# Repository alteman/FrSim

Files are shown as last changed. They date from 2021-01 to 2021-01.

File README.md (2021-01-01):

# FrSim - an STM32 wireless flight simulator USB dongle for FrSky radios

## Introduction

FrSim is a project to create a cheap and easy to build DIY wireless USB receiver dongle that supports FrSky D8/D16 protocols.
BOM is $4, all parts are readily available, no SMD soldering needed.

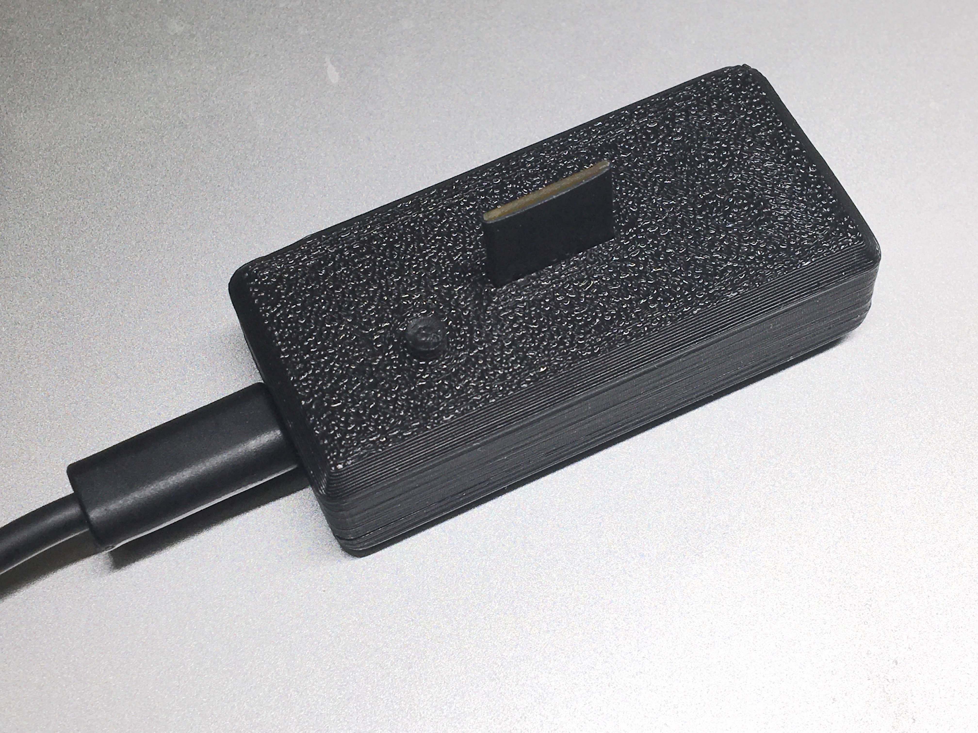
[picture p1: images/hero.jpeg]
Image of FrSim dongle in a 3D printed case


## Why make another sim dongle?

There are existing Arduino based dongles available. I don't like Arduino and didn't have any USB Arduino boards on hand, so that was out.  
There are projects that include custom PCBs, but that seemed too involved for a project that was supposed to save me the cost of a proper $20 dongle.  
There might be some projects that fit the criteria but I missed. Anyway, I didn't spend too much time on this one, and enjoyed most of it, so that wasn't a waste :)

## Parts

- An STM32 Blue Pill board (STM32F103C8T6)
- A CC2500 RF module
- That's it!
- (Optional) a bind button. I cut the Reset button trace and reused it. You might have a pushbutton or a Reed switch handy.

## Building firmware

Currently you have to use STM32CubeIDE to build it. I'm sorry. I'll add a dockerfile if I see any stars or forks :) Or submit a PR yourself!

## Flashing firmware

You can use dfu-util to flash firmware using boot0 jumper to enter DFU. I think the best way is using Betaflight flasher - everyone already have Betaflight installed and it's pretty user friendly. Just go to Firmware tab, press the Local button and load ccsim.hex after connecting the board in DFU mode.

## Schematics

You need to connect STM32 pins to the RF module according to the following 

### STM32 pins

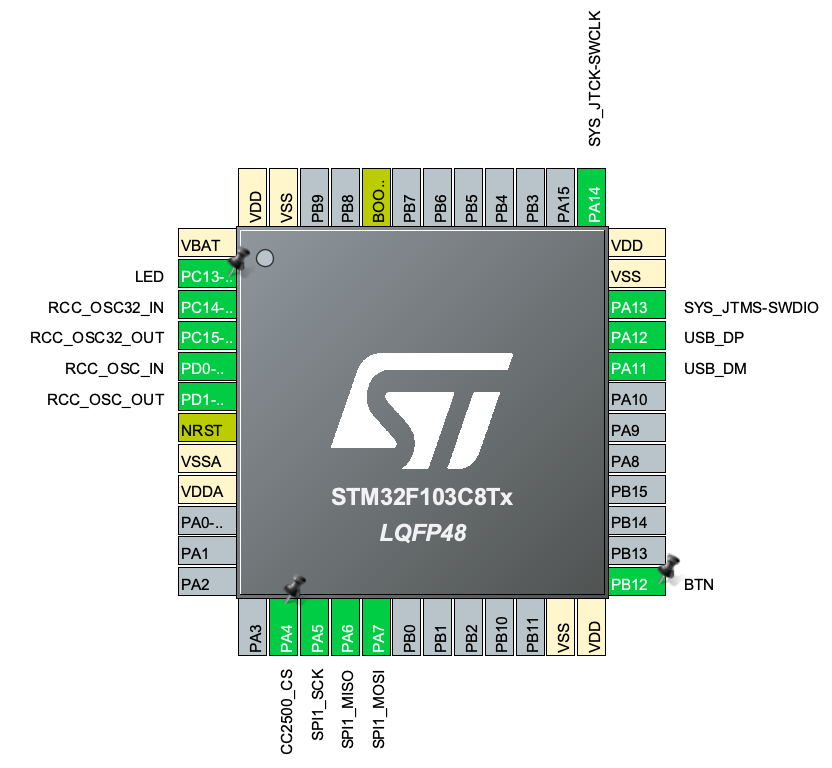
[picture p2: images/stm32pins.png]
Screenshot of STM32 pins with assignments


### CC2500 module pins

24TRGC2 - that's the module I used. If yours looks different, please research its pinout before it goes puff.

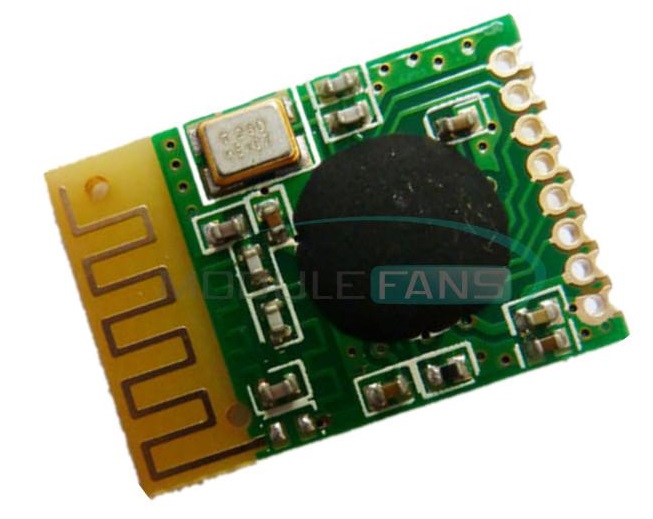
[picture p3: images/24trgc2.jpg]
Image of 24TRGC2 CC2500 module - front

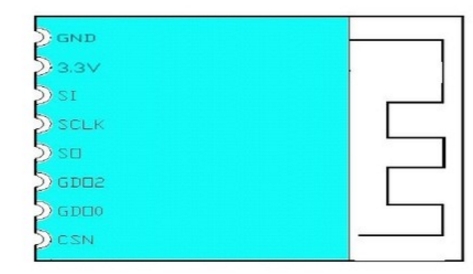
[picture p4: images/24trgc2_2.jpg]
Image of 24TRGC2 CC2500 module - back

- GND
- 3.3V
- SI - SPI MOSI
- SCLK - SPI CLK
- SO - MISO
- GDO2 - N/C
- GDO0 - N/C
- CSN - SPI chip select (inverted)

### Connections
- PA4 to CC2500_CSN
- PA5 to CC2500_CLK
- PA6 to CC2500_MISO
- PA7 to CC2500_MOSI
- PB12 to a pushbutton to GND.

## CAD files

[CAD](CAD) - CAD files (Fusion 360 source and STLs) for the case

## Using the damn thing

### Pairing
- Connect to USB while pressing the bind button
- Press Bind on the radio and wait for it to bind
- Unplug and re-plug the dongle

### RX mode
FrSky receiver mode is set to D16 V2 FCC in [frsky_rx.c](Core/Src/frsky_rx.c):  
`static uint8_t frsky_rx_format = FRSKY_RX_D16v2FCC;`.  
I haven't found a way to autodetect the receiver mode during bind and configuring a USB HID device isn't a pleasant task (there's no built-in GUI available to set parameters). Prebuilt firmware also uses that mode. Any suggestions of a user friendly way to set the RX mode are welcome.

### Calibration
Do joystick calibration the same as with wired connection.

### Controls
First 8 channels (1 to 8) are assigned to axes, next 8 (channels 9 to 16) - to buttons. Buttons are considered 'pressed' when channel value exceeds 15
00us.

## Used 3rd party code/credits

### DIY Multiprotocol Module - FrSky receiver code
[Multiprotocol TX Module](https://github.com/pascallanger/DIY-Multiprotocol-TX-Module) project - borrowed the receiver code from there. Might have been a mistake - the code was distinctly Arduino based - all source files were marked with .ino extensions as to warn others, all variables global, scattered across files, the only official way to build was from Arduino IDE (says the man who didn't provide a dockerfile..) At least the code supports D16/D16v2 protocols.  
License: GPLv3

[STM32Cube](https://www.st.com/en/ecosystems/stm32cube.html) - USB HID code and HAL library.  
License: who knows? but probably permissive.. unless you plan to use Chinese STM32 'GD32' clones :)

## License
Left as an exercise to the reader. My guess would be GPLv3 since, you know, DIY Multiprotocol is GPLv3 and that's where frsky_rx.c came from.

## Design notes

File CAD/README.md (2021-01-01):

# CAD files

[sim_case v2.f3d](./sim_case v2.f3d) - Fusion 360 source model for the case
[stl](./stl) - STL files for case parts

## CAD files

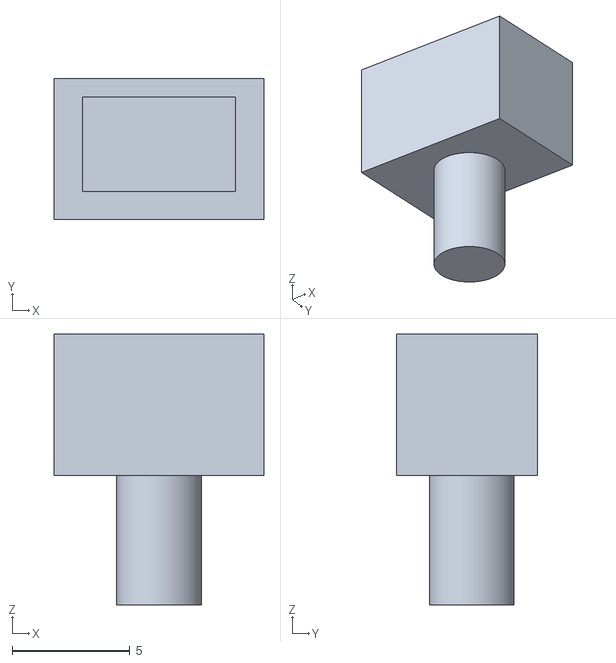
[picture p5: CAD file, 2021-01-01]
CAD/stl/sim_Button.stl
8.90 x 6.00 x 11.5

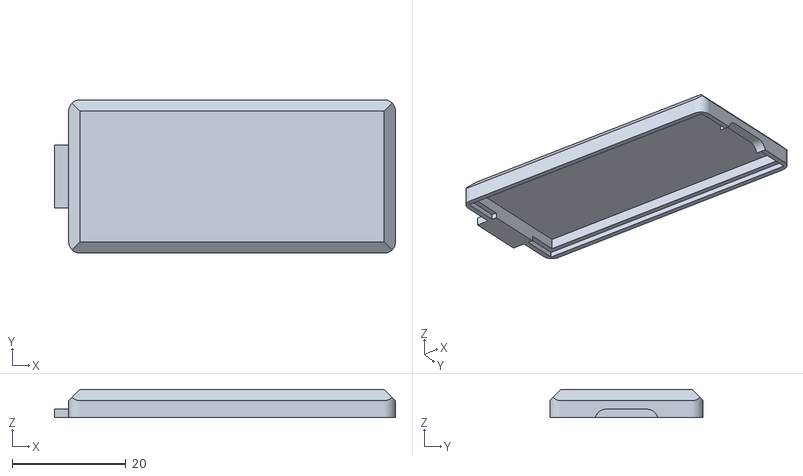
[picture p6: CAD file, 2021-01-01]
CAD/stl/sim_Cover_bottom.stl
60.0 x 27.0 x 5.00

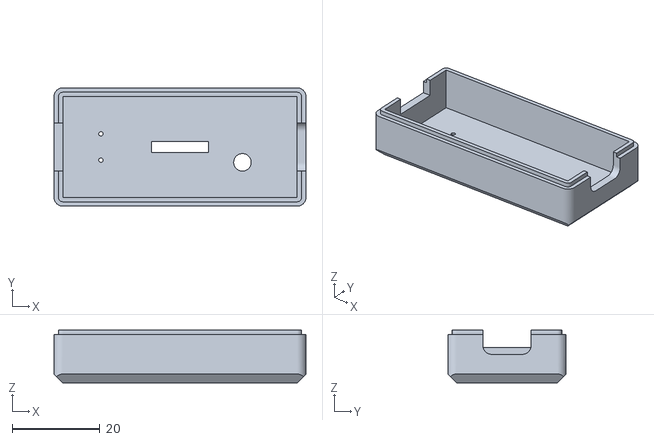
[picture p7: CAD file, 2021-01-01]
CAD/stl/sim_Cover_top.stl
57.5 x 27.0 x 12.0

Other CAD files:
CAD/sim_case v2.f3d

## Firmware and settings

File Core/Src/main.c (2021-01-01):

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
/* Includes ------------------------------------------------------------------*/
#include "main.h"
#include "cmsis_os.h"
#include "usb_device.h"

/* USER CODE BEGIN Includes */

#include "usbd_customhid.h"
extern USBD_HandleTypeDef hUsbDeviceFS;
#include "frsky_rx.h"
#include "eeprom.h"

/* USER CODE END Includes */

CRC_HandleTypeDef hcrc;

SPI_HandleTypeDef hspi1;
DMA_HandleTypeDef hdma_spi1_rx;
DMA_HandleTypeDef hdma_spi1_tx;

/* Definitions for defaultTask */
osThreadId_t defaultTaskHandle;
const osThreadAttr_t defaultTask_attributes = {
  .name = "defaultTask",
  .priority = (osPriority_t) osPriorityNormal,
  .stack_size = 128 * 4
};
void SystemClock_Config(void);
static void MX_GPIO_Init(void);
static void MX_DMA_Init(void);
static void MX_SPI1_Init(void);
static void MX_CRC_Init(void);
void StartDefaultTask(void *argument);

/**
  * @brief  The application entry point.
  * @retval int
  */
int main(void)
{
  /* MCU Configuration--------------------------------------------------------*/

  /* Reset of all peripherals, Initializes the Flash interface and the Systick. */
  HAL_Init();

  /* Configure the system clock */
  SystemClock_Config();

  /* Initialize all configured peripherals */
  MX_GPIO_Init();
  MX_DMA_Init();
  MX_SPI1_Init();
  MX_CRC_Init();
  /* USER CODE BEGIN 2 */
  EE_Init();

  /* USER CODE END 2 */

  /* Init scheduler */
  osKernelInitialize();

  /* USER CODE BEGIN RTOS_MUTEX */
  /* add mutexes, ... */
  /* USER CODE END RTOS_MUTEX */

  /* USER CODE BEGIN RTOS_SEMAPHORES */
  /* add semaphores, ... */
  /* USER CODE END RTOS_SEMAPHORES */

  /* USER CODE BEGIN RTOS_TIMERS */
  /* start timers, add new ones, ... */
  /* USER CODE END RTOS_TIMERS */

  /* USER CODE BEGIN RTOS_QUEUES */
  /* add queues, ... */
  /* USER CODE END RTOS_QUEUES */

  /* Create the thread(s) */
  /* creation of defaultTask */
  defaultTaskHandle = osThreadNew(StartDefaultTask, NULL, &defaultTask_attributes);

  /* USER CODE BEGIN RTOS_THREADS */
  /* add threads, ... */
  /* USER CODE END RTOS_THREADS */

  /* USER CODE BEGIN RTOS_EVENTS */
  /* add events, ... */
  /* USER CODE END RTOS_EVENTS */

  /* Start scheduler */
  osKernelStart();

  /* We should never get here as control is now taken by the scheduler */
  /* Infinite loop */
  /* USER CODE BEGIN WHILE */
  while (1)
  {
    /* USER CODE END WHILE */

    /* USER CODE BEGIN 3 */
  }
  /* USER CODE END 3 */
}

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
/* USER CODE BEGIN 4 */

// !! KEEP IN SYNC WITH REPORT_DESC IN CUSTOM_HID_ReportDesc_FS
#define USB_N_CHANNELS 8
//uint32_t last_ticks[0x100];
//uint8_t t;

/* USER CODE END 4 */

/* USER CODE BEGIN Header_StartDefaultTask */
/**
  * @brief  Function implementing the defaultTask thread.
  * @param  argument: Not used
  * @retval None
  */
/* USER CODE END Header_StartDefaultTask */
void StartDefaultTask(void *argument)
{
  /* init code for USB_DEVICE */
  MX_USB_DEVICE_Init();
  /* USER CODE BEGIN 5 */
  typedef struct {
	  uint32_t buttons:24;
	  uint16_t channels[USB_N_CHANNELS];
  } __attribute__((packed)) hid_report_t;
  hid_report_t hid_report = {0};
  uint8_t btn = HAL_GPIO_ReadPin(BTN_GPIO_Port, BTN_Pin);
  if (!btn) {
	  FrSky_Rx_Bind();
	  HAL_GPIO_WritePin(LED_GPIO_Port, LED_Pin, GPIO_PIN_RESET);
  }


  FrSky_Rx_init();
  uint32_t ticks = HAL_GetTick();

  /* Infinite loop */
  for(uint8_t lcnt = 0; ; ++lcnt)
  {
	  osDelayUntil(ticks);
	  uint32_t usDelay = FrSky_Rx_callback();
	  uint8_t phase = Frky_Rx_Phase();
	  uint16_t const * ch;
	  bool channelsUpdated = FrSky_Rx_Channels(&ch);
	  if (channelsUpdated) {
		  hid_report.buttons = 0;
		  for (uint8_t i = 0; i < USB_N_CHANNELS; ++i) {
			  hid_report.channels[i] = ch[i];
			  if (ch[i + USB_N_CHANNELS] > 1500) {
				  hid_report.buttons |= (1 << i);
			  }
		  }
		  USBD_CUSTOM_HID_SendReport(&hUsbDeviceFS, (uint8_t*)&hid_report, sizeof(hid_report));
	  }
	  uint32_t delayTicks = usDelay / 1000;
	  ticks += delayTicks;
	  if (phase == FRSKY_RX_DATA) {
		  uint8_t lqi = FrSky_Rx_Lqi();
		  if (lqi == 0) {
			  HAL_GPIO_WritePin(LED_GPIO_Port, LED_Pin, GPIO_PIN_SET);
		  } else {
			  if (!(lcnt & 0x1f)) {
				  if (lqi > 90 ||
						  (lqi > 70 && !(lcnt & 0x3f)) ||
						  (lqi > 50 && !(lcnt & 0x7f))) {
					  HAL_GPIO_TogglePin(LED_GPIO_Port, LED_Pin);
				  }
			  }
		  }
	  }
  }
  /* USER CODE END 5 */
}

 /**
  * @brief  Period elapsed callback in non blocking mode
  * @note   This function is called  when TIM1 interrupt took place, inside
  * HAL_TIM_IRQHandler(). It makes a direct call to HAL_IncTick() to increment
  * a global variable "uwTick" used as application time base.
  * @param  htim : TIM handle
  * @retval None
  */
void HAL_TIM_PeriodElapsedCallback(TIM_HandleTypeDef *htim)
{
  if (htim->Instance == TIM1) {
    HAL_IncTick();
  }
}

/**
  * @brief  This function is executed in case of error occurrence.
  * @retval None
  */
void Error_Handler(void)
{
  /* USER CODE BEGIN Error_Handler_Debug */
  /* User can add his own implementation to report the HAL error return state */
  __disable_irq();
  while (1)
  {
  }
  /* USER CODE END Error_Handler_Debug */
}

#ifdef  USE_FULL_ASSERT
/**
  * @brief  Reports the name of the source file and the source line number
  *         where the assert_param error has occurred.
  * @param  file: pointer to the source file name
  * @param  line: assert_param error line source number
  * @retval None
  */
void assert_failed(uint8_t *file, uint32_t line)
{
  /* USER CODE BEGIN 6 */
  /* User can add his own implementation to report the file name and line number,
     ex: printf("Wrong parameters value: file %s on line %d\r\n", file, line) */
  /* USER CODE END 6 */
}
#endif /* USE_FULL_ASSERT */

/************************ (C) COPYRIGHT STMicroelectronics *****END OF FILE****/

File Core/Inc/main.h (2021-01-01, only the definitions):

#define LED_Pin GPIO_PIN_13
#define LED_GPIO_Port GPIOC
#define CC2500_CS_Pin GPIO_PIN_4
#define CC2500_CS_GPIO_Port GPIOA
#define BTN_Pin GPIO_PIN_12
#define BTN_GPIO_Port GPIOB

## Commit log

2021-01-01 Add some documentation, prebuilt firmware and CAD files
    [sim_Button.stl, sim_Cover_bottom.stl, sim_Cover_top.stl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]
2021-01-01 Add an image with the case

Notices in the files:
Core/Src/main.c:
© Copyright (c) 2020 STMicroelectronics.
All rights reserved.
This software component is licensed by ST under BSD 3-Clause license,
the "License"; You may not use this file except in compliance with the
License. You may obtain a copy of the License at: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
